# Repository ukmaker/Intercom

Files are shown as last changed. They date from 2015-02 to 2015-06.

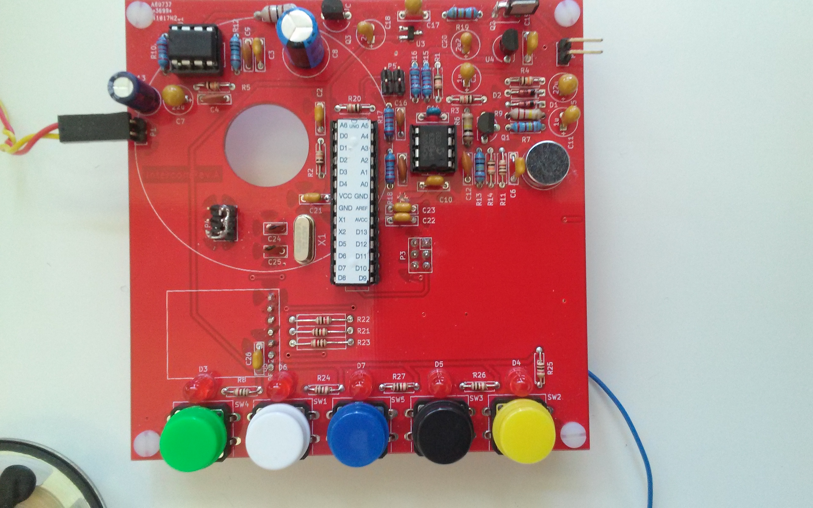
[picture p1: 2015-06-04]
Intercom_PCB_Closeup.jpg

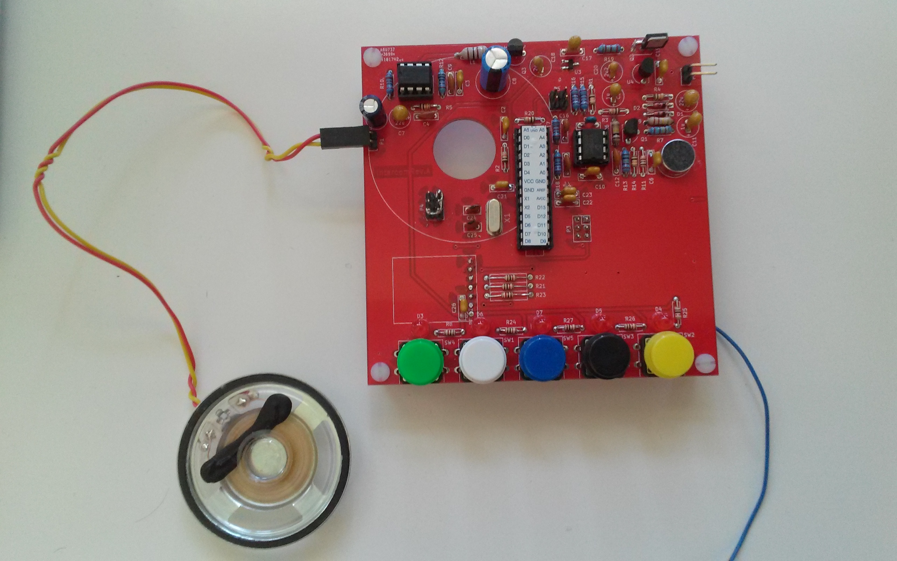
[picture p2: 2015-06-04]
Intercom_With_Speaker.jpg

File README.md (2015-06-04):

What Is it?
==================
This project implements a wireless intercom system using the RFM12B radio
module and the Atmega 328P microcontroller running the Arduino environment.

Why Does it Exist?
===================
I wanted a wireless intercom so I could stop shouting up the stairs at the kids.

The consensus on the web was that the RFM12B is not suitable for speech: challenge!

What Does It Do?
===================
Implements a five-station intercom with the following features:

  - Call each station individually (station to station)
  - Call all stations together (broadcast)
  - LED indicates which station is calling
  - Uses low power sleep modes when not in use giving up to 3 months life on a PP3 battery
  
How Does It Do It?
===================

  - Atmega 328P running at 16MHz
  - Microphone AGC circuit
  - 8-bit audio sampled at 8kHz
  - RFM12B running at 115kBaud
  - Range in excess of 20m (depends on length of aerial)

What's Wrong With It?
======================
The circuit design is fine and works well, but:

  - Battery life could be better - the RFM12B is a bit of a hog. Use a 9V wall-wart if you're bothered.
  - The PCB layout sucks. Sorry. If I had time I'd do it again using SMD parts, and I'd probably 
  use a more modern, lower power replacement for the RFM12B.
  
Dependencies
=================
Relies on my RFM12B library - a non-blocking, event-driven implementation. Get it here:

https://github.com/ukmaker/RFM12BE

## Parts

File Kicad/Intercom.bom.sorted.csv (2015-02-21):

R13 | 100K
C10 | 100n
C19 | 100n
C21 | 100n
C22 | 100n
C23 | 100n
C26 | 100n
C3 | 100n
C6 | 100n
C13 | 100u
L1 | 100u
R1 | 10K
R14 | 10K
R20 | 10K
R2 | 10K
R3 | 10K
R4 | 10K
R5 | 10K
R12 | 10R
C8 | 1200u
X1 | 16MHz
R11 | 1K
R21 | 1K
R22 | 1K
R23 | 1K
R19 | 1M
R7 | 1M
C11 | 1u
C1 | 1u
C17 | 1u
C2 | 200n
R9 | 220K
C14 | 220n
C16 | 22n
C24 | 22p
C25 | 22p
C5 | 22u
C7 | 22u
R10 | 2K2
R15 | 2K2
R16 | 2K2
R17 | 2K2
R18 | 2K2
C12 | 2n2
C18 | 2u2
C20 | 2u2
C4 | 470p
R24 | 470R
R25 | 470R
R26 | 470R
R27 | 470R
R8 | 470R
C15 | 47n
C9 | 47n
IC1 | ATMEGA328-P | DIL28
D1 | BAT43
D2 | BAT43
Q1 | BF244A | TO92
P1 | CONN_2
P2 | CONN_2
P5 | CONN_2X2
P3 | CONN_3X2
P4 | CONN_3X2
Q2 | IRFU3505
U4 | LE33CZ
D3 | LED
D4 | LED
D5 | LED
D6 | LED
D7 | LED
U1 | LM386
U3 | MCP1700T
U2 | MCP6002
MK1 | MIC9.7MM
R6 | R
U5 | RFM12B
SW1 | SW_PUSH
SW2 | SW_PUSH
SW3 | SW_PUSH
SW4 | SW_PUSH
SW5 | SW_PUSH
Reference | Value | Footprint | Datasheet
Q3 | ZTX313

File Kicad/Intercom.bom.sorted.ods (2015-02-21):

Reference | Value | Reference | Value
R13 | 100K | C18 | 2u2
C10 | 100n | C20 | 2u2
C19 | 100n | C4 | 470p
C21 | 100n | R24 | 470R
C22 | 100n | R25 | 470R
C23 | 100n | R26 | 470R
C26 | 100n | R27 | 470R
C3 | 100n | R8 | 470R
C6 | 100n | C15 | 47n
C13 | 100u | C9 | 47n
L1 | 100u | IC1 | ATMEGA328-P
R1 | 10K | D1 | BAT43
R14 | 10K | D2 | BAT43
R20 | 10K | Q1 | BF244A
R2 | 10K | P1 | CONN_2
R3 | 10K | P2 | CONN_2
R4 | 10K | P5 | CONN_2X2
R5 | 10K | P3 | CONN_3X2
R12 | 10R | P4 | CONN_3X2
C8 | 1200u | Q2 | IRFU3505
X1 | 16MHz | U4 | LE33CZ
R11 | 1K | D3 | LED
R21 | 1K | D4 | LED
R22 | 1K | D5 | LED
R23 | 1K | D6 | LED
R19 | 1M | D7 | LED
R7 | 1M | U1 | LM386
C11 | 1u | U3 | MCP1700T
C1 | 1u | U2 | MCP6002
C17 | 1u | MK1 | MIC9.7MM
C2 | 200n | R6 | R
R9 | 220K | U5 | RFM12B
C14 | 220n | SW1 | SW_PUSH
C16 | 22n | SW2 | SW_PUSH
C24 | 22p | SW3 | SW_PUSH
C25 | 22p | SW4 | SW_PUSH
C5 | 22u | SW5 | SW_PUSH
C7 | 22u | Q3 | ZTX313
R10 | 2K2
R15 | 2K2
R16 | 2K2
R17 | 2K2
R18 | 2K2
C12 | 2n2

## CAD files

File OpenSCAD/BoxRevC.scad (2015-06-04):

/**
* Intercom box rev c
* This time I might get it right.
*
* Define all panels in 2d.
* Use extrude to render in 3D to show assembly
* 2D layout can be exported to SVG for laser-cutting
**/
// Relies on using button extenders so the PCB can be 
// attached to the backplate and multiple levels are not needed
// 

// All dimensions in mm

// nice round holes
$fs=0.01;

c=5;

// kerf of the laser beam
kerf = 0;//0.2;
skerf = kerf / 2;

// Let's have a nice picture of the PCB to we can see what's going on
pcb_w = 100;
pcb_h = 100;
pcb_t = 2;
pcb_hole_t = 2.2;
pcb_hole_z = -0.1;

pcb_mth_x = 3.7;
pcb_mth_y = 3.7;
pcb_mth_x_spacing = 92.4;
pcb_mth_y_spacing = 92.7;
pcb_mth_dia = 3.0;
pcb_b_clearance = 10;
pcb_l_clearance = 5;
pcb_r_clearance = 5;
pcb_t_clearance = 10;

pcb_btn_x_spacing = 17.15;
// position of first button (is this right?)
pcb_btn_x = 15.5;
pcb_btn_y = 6.1;

btn_body_dia = 11.5;
btn_hole_dia = 12 - skerf;
btn_body_t = 4.5;

btn_rim_dia = 13;
btn_rim_t = 1.5;

btn_base_w = 10;
btn_base_h = 10;
btn_base_t = 3;
btn_ext_w = 8;
btn_ext_h = 8;
btn_ext_t = 18;


speaker_dia = 50;
speaker_inner_dia = 22;

speaker_x = 30;
speaker_y = 68;

spi_connector_top_y = 53;
spi_connector_bottom_y = 40;
spi_connector_left_x = 60;
spi_connector_width = 5;
spi_connector_height = 8;
spi_connector_base_t = 2;
spi_connector_pin_t = 8;
spi_connector_pin_w = 0.8;
spi_hole_w = 9;
spi_hole_h = 15;
spi_hole_x = 58;
spi_hole_y = 36;

microphone_x = 91.0;
microphone_y = 63.0;
microphone_dia = 8;
microphone_t = 5;

tenth_in = 2.54;
thickness = 4;

top_panel_t = 4;
top_panel_h = pcb_h + pcb_b_clearance + pcb_t_clearance;
top_panel_w = pcb_w + pcb_r_clearance + pcb_l_clearance + 2 * thickness;


tongue_length = 20;
tongue_depth = thickness;

box_h = btn_ext_t 
	+ 1 * top_panel_t 
	+ btn_base_t + btn_rim_t
	+ pcb_t 
	+ spi_connector_pin_t;


base_z = -spi_connector_pin_t;// - top_panel_t;

top_bottom_gap = pcb_t+btn_base_t+btn_ext_t+btn_rim_t + spi_connector_pin_t;
side_panel_h = top_bottom_gap + 2*top_panel_t;

side_panel_tongue_offset = 
  ((side_panel_h - 2*top_panel_t) - tongue_length) / 2;

side_panel_ul_groove_xy = 
  (side_panel_h - tongue_length) / 2;

ul_panel_h = side_panel_h - 2 * top_panel_t;

// Top-level 2D modules
// The PCB mounting holes
// A separate module since we need them on the bottom box plate as well
module mounting_holes() {
		mounting_hole(pcb_mth_x,                   pcb_mth_y);
		mounting_hole(pcb_mth_x+pcb_mth_x_spacing, pcb_mth_y);
		mounting_hole(pcb_mth_x+pcb_mth_x_spacing, pcb_mth_y+pcb_mth_y_spacing);
		mounting_hole(pcb_mth_x,                   pcb_mth_y+pcb_mth_y_spacing);
}

module mounting_hole(x, y) {
	translate([x,y,0])
	circle(r=pcb_mth_dia/2);
}

// The PCB with the speaker outline and hole
module pcb() {

	difference() {
        square([pcb_w, pcb_h]);
		translate([speaker_x, speaker_y,  0]) color("Blue") speaker_hole();
        mounting_holes();
    }

    // a circle to show where the speaker goes
    color("Black")
	translate([speaker_x, speaker_y,  0]) {
        difference() {
            circle(r=speaker_dia/2);
            circle(r=(speaker_dia/2)-1);
        }
    }
    
    // a circle to show where the microphone goes
    	
	color("Black")
	translate([microphone_x,microphone_y,0]) {
        difference() {
            circle(r=microphone_dia/2);
            circle(r=(microphone_dia/2)-1);
        }
    }
}

module speaker_hole() {
		circle(r=speaker_inner_dia/2);
}

module tongue() {
    square([tongue_length, tongue_depth]);
}

module spi_connector() {

	translate([spi_connector_left_x, spi_connector_bottom_y, -spi_connector_base_t])
	color("black")
	cube([spi_connector_width, spi_connector_height, spi_connector_base_t]);
	color("Gold") {
		// the pins
		spi_pin(spi_connector_left_x,          spi_connector_bottom_y);
		spi_pin(spi_connector_left_x+tenth_in, spi_connector_bottom_y);

		spi_pin(spi_connector_left_x,          spi_connector_bottom_y+tenth_in);
		spi_pin(spi_connector_left_x+tenth_in, spi_connector_bottom_y+tenth_in);

		spi_pin(spi_connector_left_x,          spi_connector_bottom_y+2*tenth_in);
		spi_pin(spi_connector_left_x+tenth_in, spi_connector_bottom_y+2*tenth_in);

	}
}

module spi_pin(x,y) {
	translate([x+1,y+1,-spi_connector_pin_t])
		cube([spi_connector_pin_w, spi_connector_pin_w, spi_connector_pin_t]);
}

// The blank for the top or bottom
module top_bottom() {
    
    square([top_panel_w, top_panel_h]);
	
	translate([tongue_length,-tongue_depth,0])
		tongue();
	
	translate([top_panel_w-2*tongue_length, -tongue_depth,0])
		tongue();
	
	translate([tongue_length,top_panel_h,0])
		tongue();
	
	translate([top_panel_w-2*tongue_length, top_panel_h,0])
		tongue();
	
}

module bottom() {
    difference() {
		translate([-(pcb_l_clearance + thickness),-(pcb_b_clearance+thickness),0]) 
        top_bottom();
        mounting_holes();
        spi_hole();
    }
}


module spi_hole() {
    translate([spi_hole_x, spi_hole_y,0])
    square([spi_hole_w, spi_hole_h]);
}

module top_microphone_hole(vec) {
	
	translate([vec[0]+microphone_x,vec[1]+microphone_y,0])
		circle(r=0.5);
}

module top_speaker_hole(vec) {
	
	translate([vec[0]+speaker_x,vec[1]+speaker_y,0])
		circle(r=0.6);
}

function point(radius, theta) =
 [radius * cos(theta), radius * sin(theta)];

module top_microphone_holes() {
	for(s = [ [0,1], [4,8]]) {

		for(i = [0:1:s[1]-1]) {
            top_microphone_hole(point(s[0], i*360/s[1]));
		}
	}
}

module top_speaker_holes() {
	for(s = [ [0,1], [5,8], [10, 16], [15, 24], [20, 32]]) {

		for(i = [0:1:s[1]-1]) {
            top_speaker_hole(point(s[0], i*360/s[1]));
		}
	}
}

module button_hole(x,y) {
    translate([x,y,0]) circle(r=btn_hole_dia/2);
}

module button_holes() {
    button_hole(pcb_btn_x + pcb_btn_x_spacing*0,pcb_btn_y);
    button_hole(pcb_btn_x + pcb_btn_x_spacing*1,pcb_btn_y);
    button_hole(pcb_btn_x + pcb_btn_x_spacing*2,pcb_btn_y);
    button_hole(pcb_btn_x + pcb_btn_x_spacing*3,pcb_btn_y);
    button_hole(pcb_btn_x + pcb_btn_x_spacing*4,pcb_btn_y);
}

module top_holes() {
    button_holes();
    top_microphone_holes();
    top_speaker_holes();
}

module top() {
	
	difference() {
		translate([-(pcb_l_clearance + thickness),-(pcb_b_clearance+thickness),0]) 
        top_bottom();
        top_holes();
	}
}

module upper_lower() {
	
    difference() {
        // basic upper or lower panel
        square([top_panel_w, side_panel_h]);
        
        upper_lower_grooves();

        // Remove the tongues at the left and right
        translate([0, side_panel_ul_groove_xy, 0])
          groove_l();
        
        translate([top_panel_w-tongue_depth, side_panel_ul_groove_xy,0])
          groove_r();
	}
}

module upper_lower_grooves() {
    // remove the lower grooves
    translate([tongue_length,0,0])
       groove_b();
    
    translate([top_panel_w-2*tongue_length,0])
        groove_b();

 
    // remove the upper grooves
    translate([tongue_length,side_panel_h-tongue_depth,0])
       groove_t();
    
    translate([top_panel_w-2*tongue_length,side_panel_h-tongue_depth,0])
        groove_t();

 
}

module groove_l() {
    remove_l(tongue_depth,tongue_length);
}
module groove_r() {
    remove_r(tongue_depth,tongue_length);
}

module groove_t() {
    remove_t(tongue_length,tongue_depth);
}
module groove_b() {
    remove_b(tongue_length,tongue_depth);
}

module remove_l(w,h) {
    // actual shape needs to be smaller by the amount of kerf
    // and moved to leave space for the kerf
    translate([-skerf,skerf,0])
    square([w+kerf,h-kerf]);
}

module remove_r(w,h) {
    // actual shape needs to be smaller by the amount of kerf
    // and moved to leave space for the kerf
    translate([skerf,skerf,0])
    square([w+kerf,h-kerf]);
}

module remove_t(w,h) {
    // actual shape needs to be smaller by the amount of kerf
    // and moved to leave space for the kerf
    translate([skerf,skerf,0])
    square([w-kerf,h+kerf]);
}

module remove_b(w,h) {
    // actual shape needs to be smaller by the amount of kerf
    // and moved to leave space for the kerf
    translate([skerf,-skerf,0])
    square([w-kerf,h+kerf]);
}

module left_right() {
    square([ul_panel_h, top_panel_h]);
    
    translate([side_panel_tongue_offset,-tongue_depth, 0])
      tongue();
    translate([side_panel_tongue_offset,top_panel_h, 0])
      tongue();
}
 

//translate([0,0,-1]) bottom();
//pcb();
//translate([0,0,1]) top();

//left_right();

//upper_lower();

module perspex(alpha=1)
{
	h = thickness;
	color("White",alpha) 
        linear_extrude(height=h,convexity=c,center=true) 
            for (i = [0 : $children-1]) children(i);
}

module assembled() {
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

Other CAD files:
OpenSCAD/BoxRevA.scad
OpenSCAD/BoxRevB.scad

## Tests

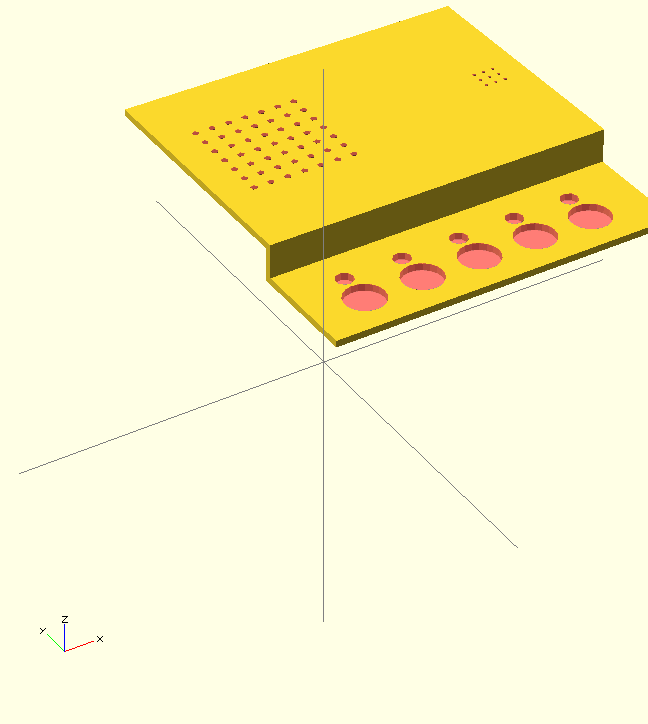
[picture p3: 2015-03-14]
OpenSCAD/test.png

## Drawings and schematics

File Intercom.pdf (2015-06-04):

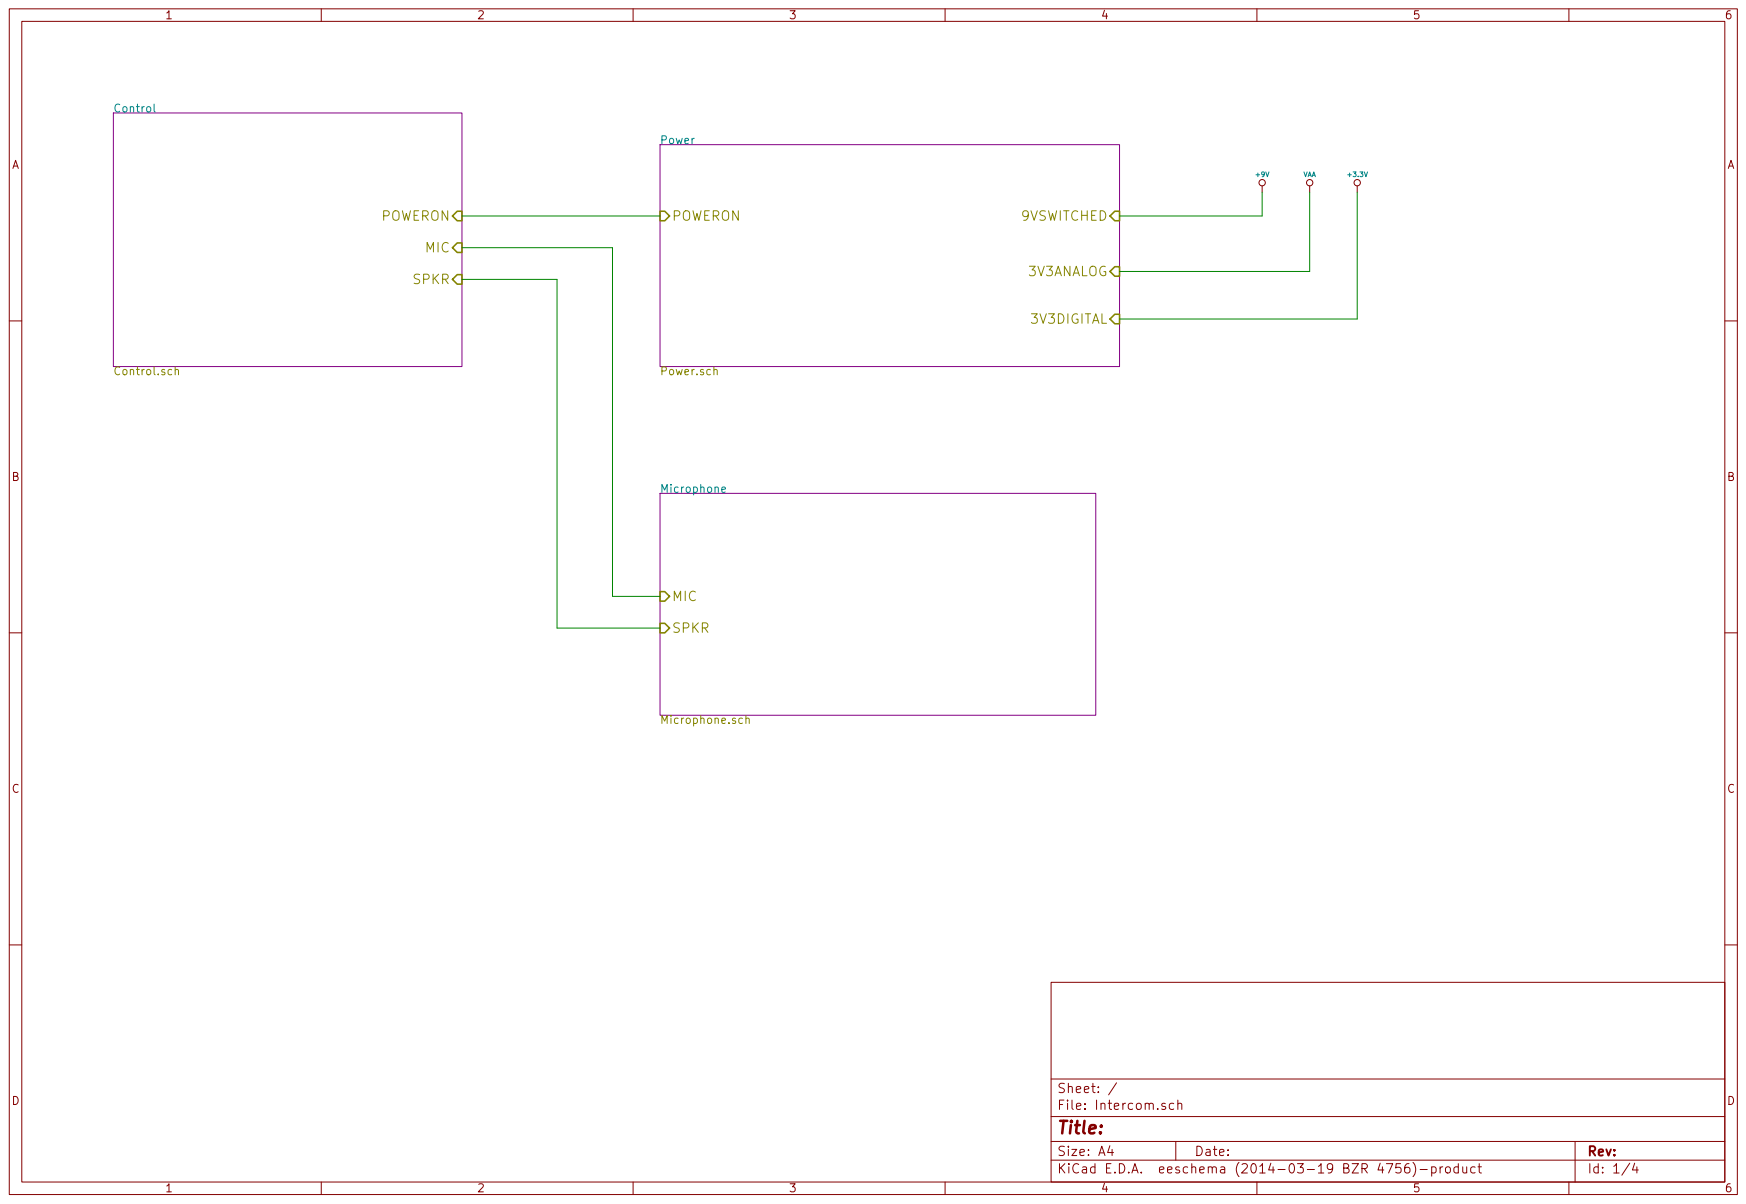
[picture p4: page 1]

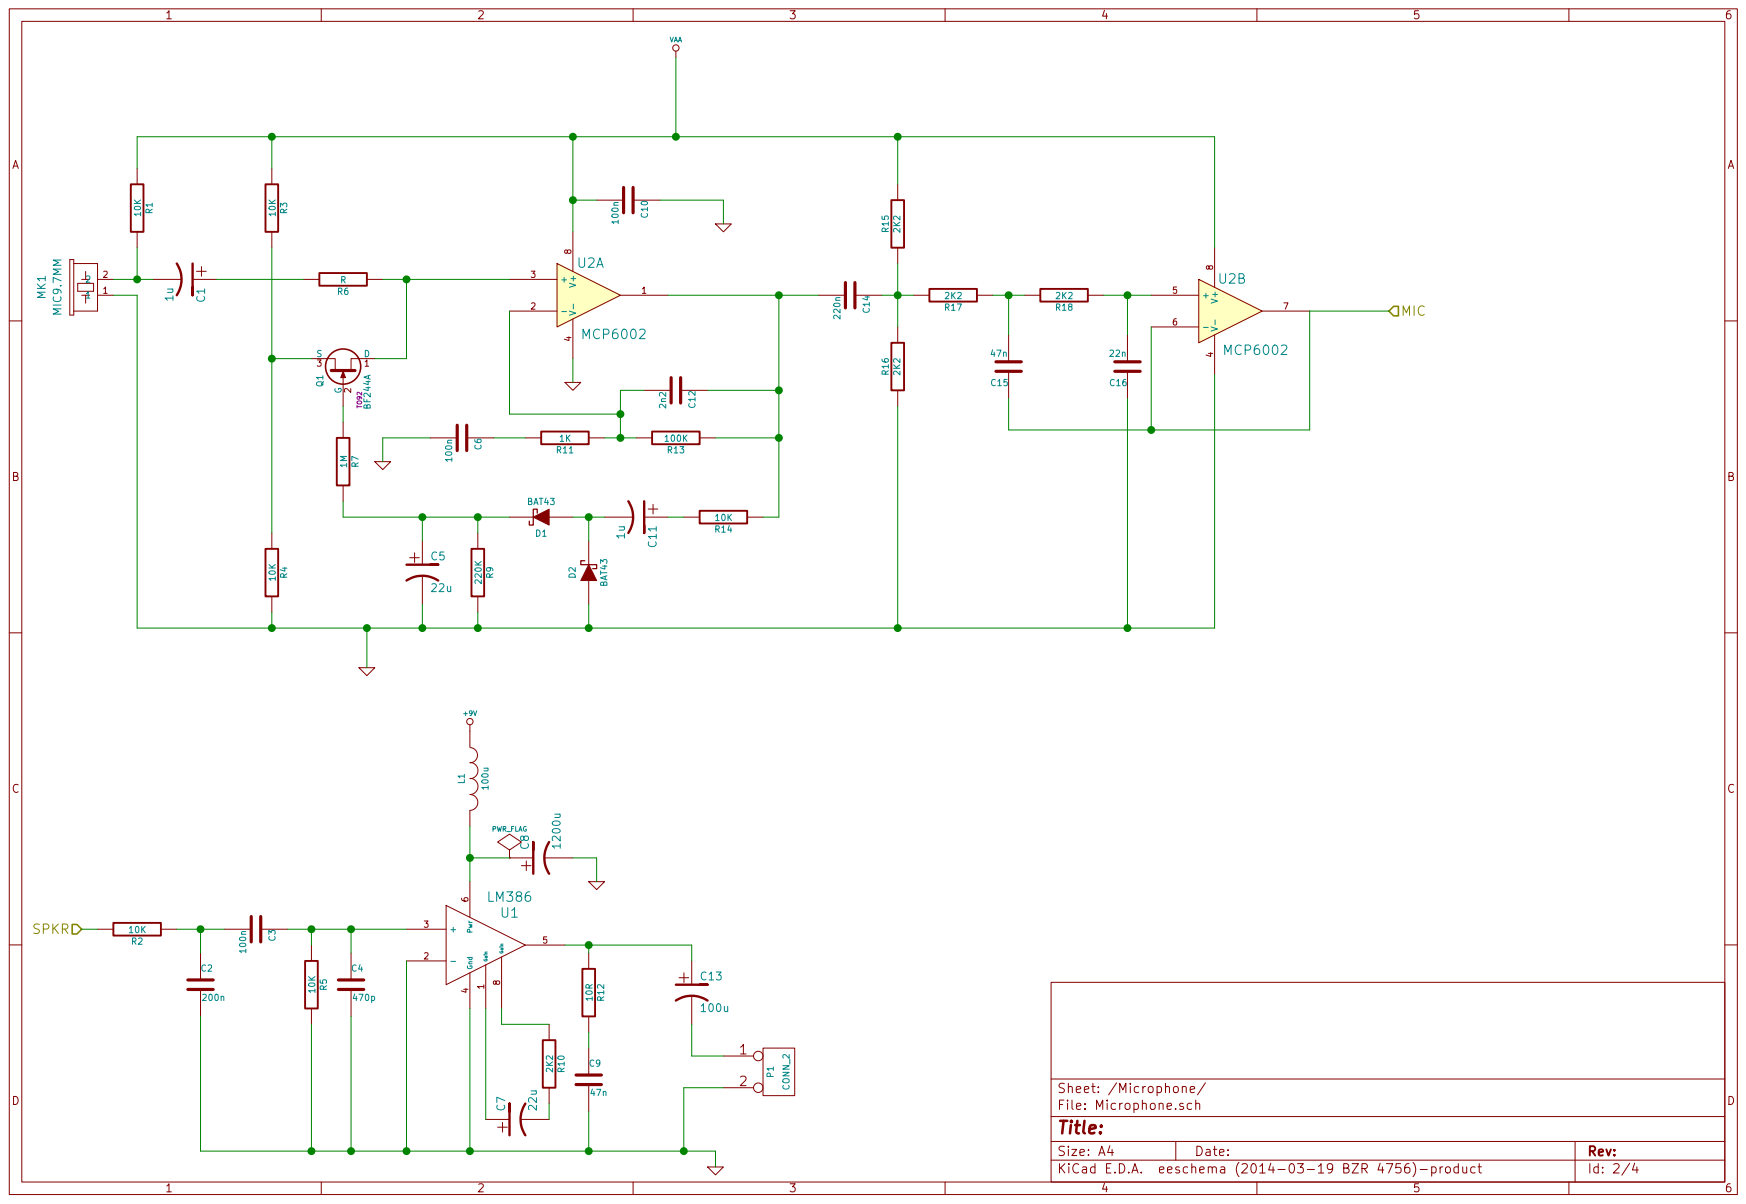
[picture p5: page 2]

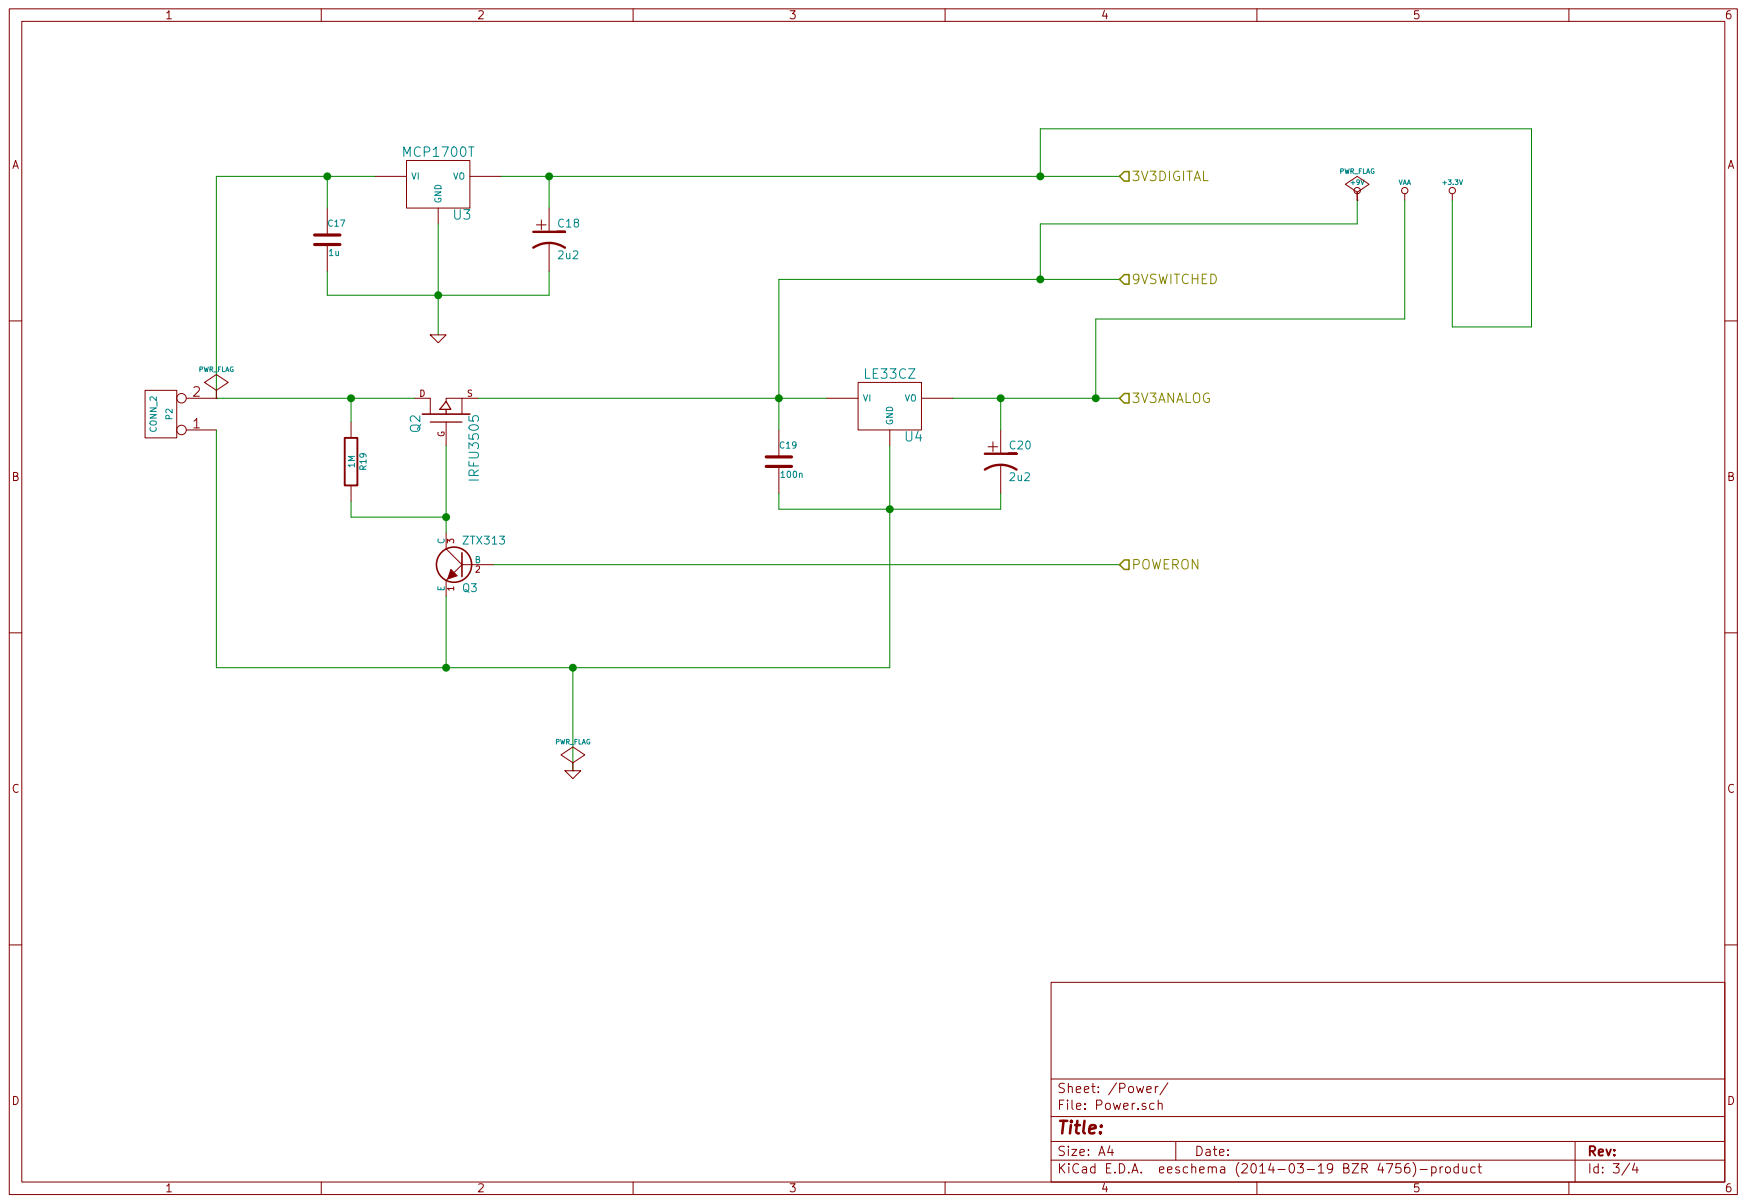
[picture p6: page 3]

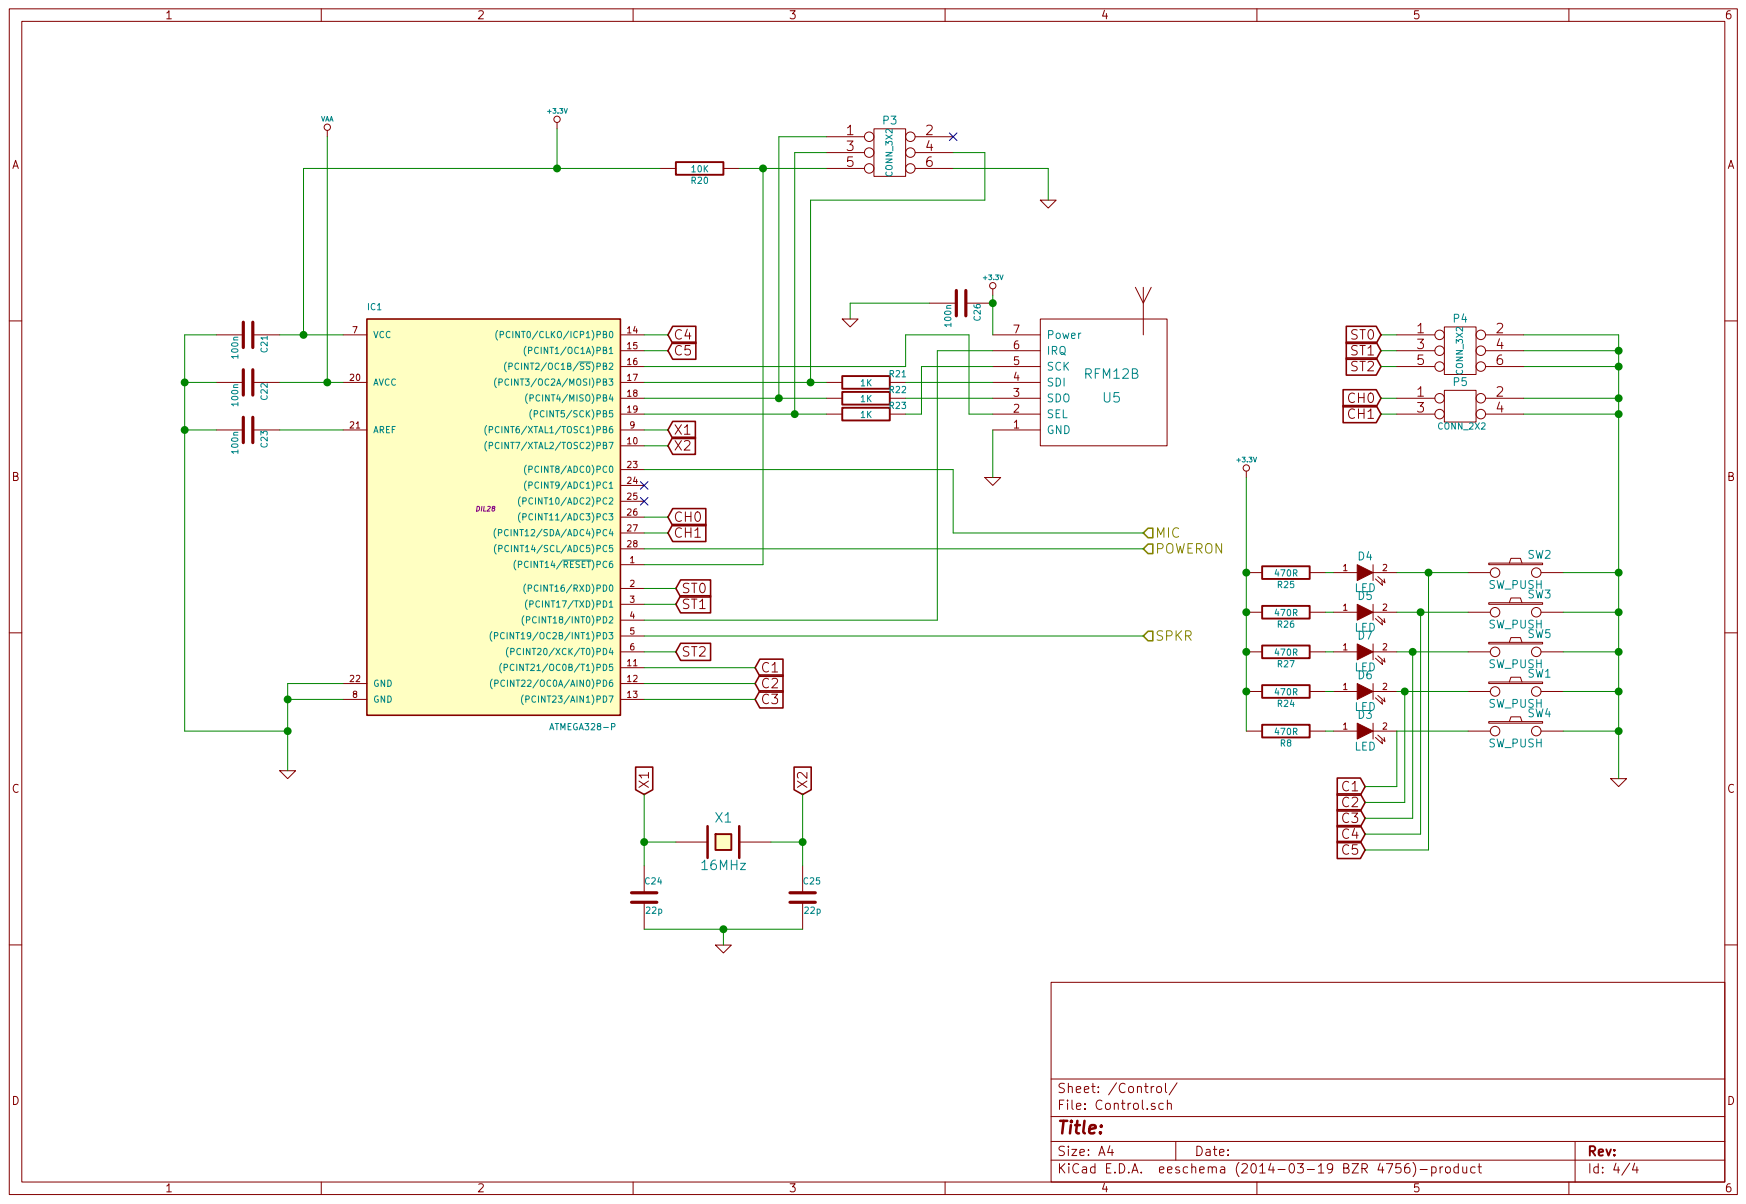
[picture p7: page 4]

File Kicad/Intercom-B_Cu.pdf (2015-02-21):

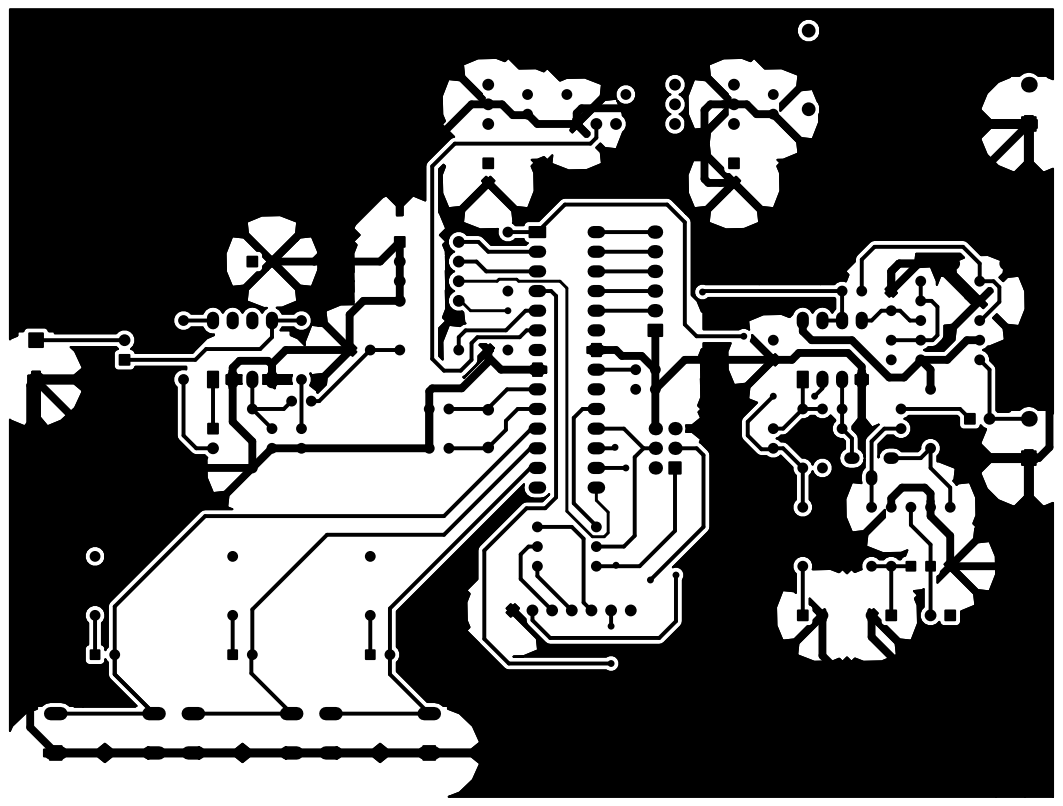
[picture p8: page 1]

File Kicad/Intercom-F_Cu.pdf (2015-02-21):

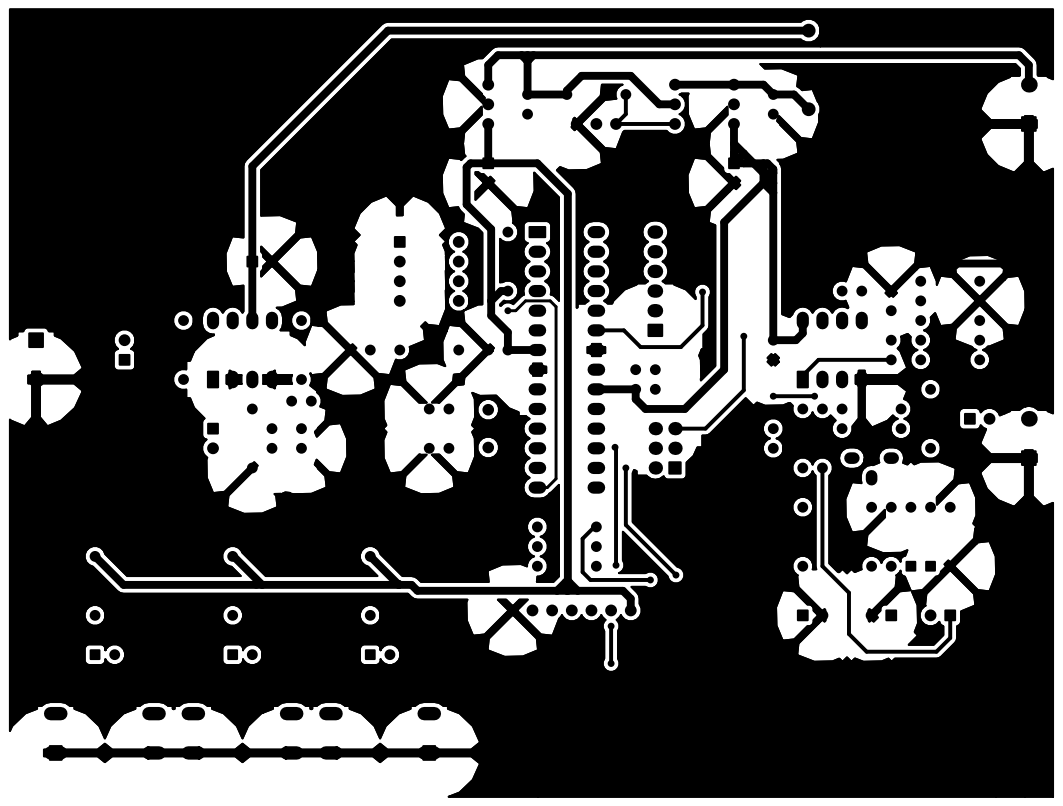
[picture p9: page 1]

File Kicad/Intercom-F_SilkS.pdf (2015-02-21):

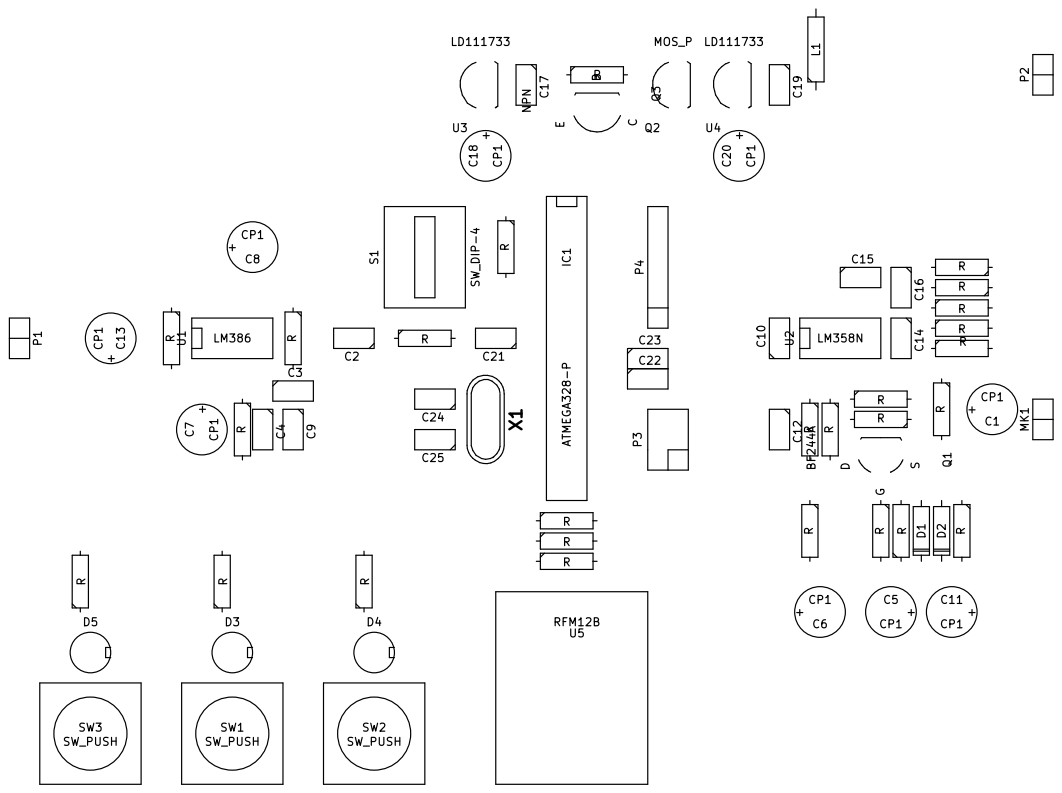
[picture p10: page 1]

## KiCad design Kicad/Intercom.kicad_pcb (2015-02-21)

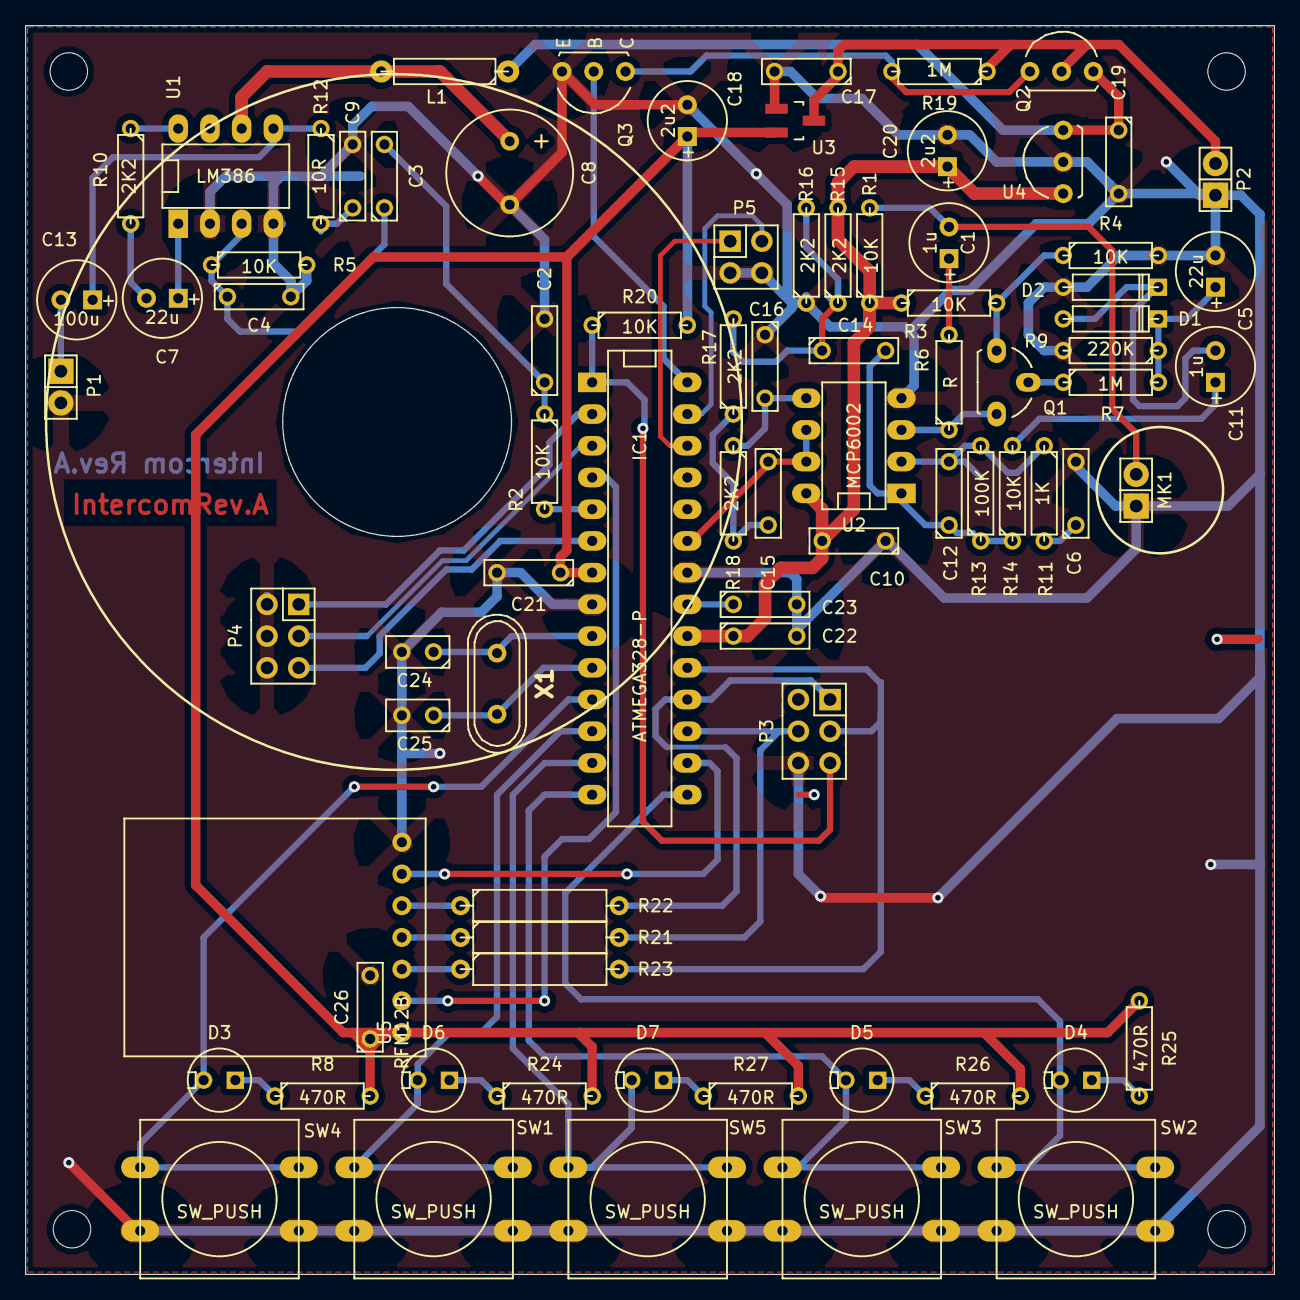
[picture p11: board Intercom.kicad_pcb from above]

Board: 2 copper layers, 100.0 x 100.0 mm, 86 parts (0 on the bottom side), 59 nets.

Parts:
C1, C11: 1u; C1V7
C2: 200n; C2
C3, C6, C10, C19, C21, C22, C23, C26: 100n; C2
C4: 470p; C2
C5, C7: 22u; C1V7
C8: 1200u; Elko_vert_20x10mm_RM5
C9, C15: 47n; C2
C12: 2n2; C2
C13: 100u; C1V7
C14: 220n; C2
C16: 22n; C2
C17: 1u; C2
C18, C20: 2u2; C1V7
C24, C25: 22p; C1
D1, D2: BAT43; D3
D3, D4, D5, D6, D7: LED; LEDV
IC1: ATMEGA328-P; DIP-28__300_ELL
L1: 100u; R4-LARGE_PADS
MK1: MIC9.7MM; Socket_Strip_Straight_1x02
MountingHole_3mm, MountingHole_3mm#2, MountingHole_3mm#3, MountingHole_3mm#4: VAL**; MountingHole_3mm
P1, P2: CONN_2; Socket_Strip_Straight_1x02
P3, P4: CONN_3X2; Socket_Strip_Straight_2x03
P5: CONN_2X2; Socket_Strip_Straight_2x02
Q1: BF244A; TO-92-FET-molded-wide-oval-SGD
Q2: IRFU3505; TO-92-Free-inline-wide
Q3: ZTX313; TO-92-Bipolar-inline-wide-CBE
R1, R2, R3, R4, R5, R14, R20: 10K; R3
R6: R; R3
R7, R19: 1M; R3
R8, R24, R25, R26, R27: 470R; R3
R9: 220K; R3
R10, R15, R16, R17, R18: 2K2; R3
R11: 1K; R3
R12: 10R; R3
R13: 100K; R3
R21, R22, R23: 1K; R5
SW1, SW2, SW3, SW4, SW5: SW_PUSH; SW_PUSH-12mm
U1: LM386; DIP-8__300_ELL
U2: MCP6002; DIP-8__300_ELL
U3: MCP1700T; SOT23_Transistor_Handsoldering_RevB_14Mar2014
U4: LE33CZ; TO-92-Free-inline-wide
U5: RFM12B
X1: 16MHz; Crystal_HC49-U_Vertical

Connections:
+3.3V: C18.1, C21.1, C26.1, IC1.7, R8.2, R20.2, R24.2, R25.2, R26.2, R27.2, U3.VO, U5.7
+9V: C19.1, L1.1, Q2.S, U4.VI
/Control/MIC: C15.1, IC1.23, U2.6, U2.7
/Control/POWERON: IC1.28, Q3.2
/Control/SPKR: IC1.5, R2.2
C1: D3.2, IC1.11, SW4.1
C2: D6.2, IC1.12, SW1.1
C3: D7.2, IC1.13, SW5.1
C4: D5.2, IC1.14, SW3.1
C5: D4.2, IC1.15, SW2.1
CH0: IC1.26, P5.1
CH1: IC1.27, P5.3
GND: C2.2, C4.2, C5.2, C6.2, C8.2, C9.2, C10.1, C16.1, C17.2, C18.2, C19.2, C20.2, C21.2, C22.2, C23.2, C24.2, C25.2, C26.2, D2.1, IC1.8, IC1.22, MK1.1, P1.2, P2.1, P3.6, P4.2, P4.4, P4.6, P5.2, P5.4, Q3.1, R4.2, R5.2, R9.2, R16.1, SW1.2, SW2.2, SW3.2, SW4.2, SW5.2, U1.2, U1.4, U2.4, U3.GND, U4.GND, U5.1
unnamed: C1.1, R6.2
unnamed: C1.2, MK1.2, R1.2
unnamed: C2.1, C3.2, R2.1
unnamed: C3.1, C4.1, R5.1, U1.3
unnamed: C5.1, D1.2, R7.2, R9.1
unnamed: C6.1, R11.2
unnamed: C7.1, U1.1
unnamed: C7.2, R10.2
unnamed: C8.1, L1.2, U1.6
unnamed: C9.1, R12.2
unnamed: C11.1, R14.2
unnamed: C11.2, D1.1, D2.2
unnamed: C12.1, C14.2, R13.1, R14.1, U2.1
unnamed: C12.2, R11.1, R13.2, U2.2
unnamed: C13.1, R12.1, U1.5
unnamed: C13.2, P1.1
unnamed: C14.1, R15.1, R16.2, R17.2
unnamed: C15.2, R17.1, R18.2
unnamed: C16.2, R18.1, U2.5
unnamed: C17.1, P2.2, Q2.D, R19.1, U3.VI
unnamed: C23.1, IC1.21
unnamed: D3.1, R8.1
unnamed: D4.1, R25.1
unnamed: D5.1, R26.1
unnamed: D6.1, R24.1
unnamed: D7.1, R27.1
unnamed: IC1.1, P3.5, R20.1
unnamed: IC1.4, U5.6
unnamed: IC1.16, U5.2
unnamed: IC1.17, P3.4, R21.2
unnamed: IC1.18, P3.1, R22.2
unnamed: IC1.19, P3.3, R23.2
unnamed: Q1.1, R6.1, U2.3
unnamed: Q1.2, R7.1
unnamed: Q1.3, R3.2, R4.1
unnamed: Q2.G, Q3.3, R19.2
unnamed: R10.1, U1.8
unnamed: R21.1, U5.4
unnamed: R22.1, U5.3
unnamed: R23.1, U5.5
ST0: IC1.2, P4.1
ST1: IC1.3, P4.3
ST2: IC1.6, P4.5
VAA: C10.2, C20.1, C22.1, IC1.20, R1.1, R3.1, R15.2, U2.8, U4.VO
X1: C24.1, IC1.9, X1.1
X2: C25.1, IC1.10, X1.2

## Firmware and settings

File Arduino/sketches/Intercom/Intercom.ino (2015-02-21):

#include <Board.h>
#include <RFM12BE.h>
#include <Interface.h>

#include <avr/sleep.h>
#include <avr/power.h>

// For RFM12B
#define NETWORKID 99

// Size of the audio buffer
#define BUFSIZE 64
// Baud rate of the radio
#define RFM_115KBAUD 3

#define INTERCOM_MODE_START_RX 1
#define INTERCOM_MODE_RX 2
#define INTERCOM_MODE_TX 3

// The delay between received packets should be less than this
#define RX_TIMEOUT_TICKS 64

// If no activity for one second, go back to sleep
#define IDLE_TIMEOUT_TICKS 8000

// Events for the whole intercom
#define INTERCOM_EVENT_TX_BUF_FULL   0x01
#define INTERCOM_EVENT_IDLE_TIMEOUT  0x02
#define INTERCOM_EVENT_RX_TIMEOUT    0x04

RFM12BE radio;
Board board;
Interface interface;


// Volatile variables are modified by the ISRs
volatile bool txBufReady;
volatile bool dacDataAvailable = false;
volatile uint8_t intercomEvents;
volatile bool wokenByRx = false;
volatile int bufPtr;

uint8_t* buf;


int intercomMode = INTERCOM_MODE_START_RX;

unsigned long debounceTicks = 0;
unsigned long lastPacketReceivedTicks = 0;
unsigned long startedIdlingTicks = 0;

int destination = -1;



void setup() {

    // switch off analog comparator to save a bit of power
    ACSR = B10000000;

    lastPacketReceivedTicks=0;
    startedIdlingTicks=0;

    board.initialise();
    board.startTimers();
    board.setButtonDownHandler(buttonDownEventHandler);
    board.setButtonUpHandler(buttonUpEventHandler);

    radio.setInterface(&interface);
    radio.initialise(board.boardId, RF12_433MHZ, NETWORKID, 0 , RFM_115KBAUD, 0);
    radio.registerEventHandler(EVENT_RX_PACKET, packetReceivedEventHandler);
    radio.registerEventHandler(EVENT_TX_READY, packetSentEventHandler);

    attachInterrupt(0, radioInterruptHandler, LOW);

    radio.startReceive();
    board.setDACEnabled(true);
}

void loop() {

    // button events override everything else
    board.handleButtonEvents();

    // handle radio events
    radio.dispatchEvents();

    updateTimeouts();       
    handleTimeoutEvents();
}


bool buttonDownEventHandler() {

    // Turn on the ADC
    board.setDACEnabled(false);
    intercomEvents = 0;
    board.setAnalogEnabled(true);

    // abort any current radio operations and get ready to send
    buf = radio.startTransmit();
    bufPtr=0;
    intercomMode = INTERCOM_MODE_TX;
    board.setADCEnabled(true);
    // Turn off any LEDs which were on because we my have been in receive mode
    // otherwise we'll stay stuck in tx forever
    board.initialiseButtons();
    destination = board.readButtons();
    return true;
}

bool buttonUpEventHandler() {

    // stop the ADC interrupt handler
    board.setADCEnabled(false);
    intercomEvents = 0;
    // stop the radio transmitter and start receiving
    radio.startReceive();
    intercomMode = INTERCOM_MODE_START_RX;
    // turn off the analog for now - no point in using power until we
    // have received a packet to playback
    board.setAnalogEnabled(false);
    board.setDACEnabled(true);
    return true;
}

bool packetReceivedEventHandler() {
    buf = radio.getBuffer();
    bufPtr = 0;

    if(intercomMode == INTERCOM_MODE_START_RX) {
        board.setAnalogEnabled(true);
        board.setDACEnabled(true);
        intercomMode = INTERCOM_MODE_RX;
    }
    lastPacketReceivedTicks = board.ticks;
    board.showSource(radio.getSenderId());
    dacDataAvailable = true;

    return true;
}

bool packetSentEventHandler() {

    if(intercomEvents & INTERCOM_EVENT_TX_BUF_FULL) {
        // ready to send the next packet
        radio.send(board.buttons, BUFSIZE);
        intercomEvents &= ~INTERCOM_EVENT_TX_BUF_FULL;
        // finished with this event
        return true;
    }

    // haven't finished with this radio event yet
    return false;
}

bool updateTimeouts() {

    if((intercomMode != INTERCOM_MODE_RX) && (intercomMode != INTERCOM_MODE_START_RX)) {
        return false;
    }

    uint16_t delay = board.ticks - lastPacketReceivedTicks;

    if((intercomMode == INTERCOM_MODE_START_RX) && (delay > IDLE_TIMEOUT_TICKS)) {
        intercomEvents |= INTERCOM_EVENT_IDLE_TIMEOUT;
    } 
    else if(delay > RX_TIMEOUT_TICKS) {
        intercomEvents |= INTERCOM_EVENT_RX_TIMEOUT;
    }
}

void rxTimeoutEventHandler() {
    board.setAnalogEnabled(false);
    board.initialiseButtons();
    intercomMode = INTERCOM_MODE_START_RX;
}

void handleTimeoutEvents() {
    if(intercomEvents & INTERCOM_EVENT_RX_TIMEOUT) {
        rxTimeoutEventHandler();
        intercomEvents &= ~INTERCOM_EVENT_RX_TIMEOUT;
    }

    if(intercomEvents & INTERCOM_EVENT_IDLE_TIMEOUT) {
        idleTimeoutEventHandler();
        intercomEvents &= ~INTERCOM_EVENT_IDLE_TIMEOUT;
    }
}

void idleTimeoutEventHandler() {
    byte adcsra = ADCSRA;
    byte admux = ADMUX;
    byte didr0 = DIDR0;
    byte didr1 = DIDR1;
    byte prr = PRR;

    // Turn off power to the analog section
    board.setAnalogEnabled(false);

    // put the radio into snooze mode
    // so that it wakes up every 350ms to check for a packet
    radio.sleepLDC(0x0260,1);

    noInterrupts();
    sleep_enable();
    set_sleep_mode(SLEEP_MODE_PWR_DOWN);

    // stop watch-dog timer
    /* Clear WDRF in MCUSR */
    MCUSR &= ~(1<<WDRF);
    /* Write logical one to WDCE and WDE */
    /* Keep old prescaler setting to prevent unintentional time-out */
    WDTCSR |= (1<<WDCE) | (1<<WDE);
    /* Turn off WDT */
    WDTCSR = 0x00;  

    // make sure no digital inputs are enabled on the analog pins
    DIDR0 = 0;
    DIDR1 = 0;

    // switch off the adc
    ADCSRA =0;
    ADMUX=0;

    PRR=0XFF;

    // attach a wakeup handler to the radio int pin
    attachInterrupt(0, wokenByRxInterruptHandler, LOW);
    wokenByRx = false;

    // turn off brown-out enable in software
    MCUCR = bit (BODS) | bit (BODSE);  // turn on brown-out enable select
    MCUCR = bit (BODS);        // this must be done within 4 clock cycles of above
    interrupts ();             // guarantees next instruction executed
    sleep_cpu ();              // sleep within 3 clock cycles of above
    //noInterrupts();  
    // Back from sleep here
    // Re-enable the hardware we were using
    sleep_disable();
    ADMUX = admux;
    ADCSRA = adcsra;
    PRR = prr;
    DIDR0 = didr0;
    DIDR1 = didr1;
    powerUp();
}

void wokenByRxInterruptHandler() {
    sleep_disable();
    detachInterrupt(0);
    wokenByRx = true;
}

void powerUp() {

    radio.wakeup();
    attachInterrupt(0, radioInterruptHandler, LOW);

    if(wokenByRx) {
        intercomMode = INTERCOM_MODE_START_RX;
        lastPacketReceivedTicks = board.ticks;
    } 
    else {
        intercomMode = INTERCOM_MODE_TX;
    }
}

void radioInterruptHandler() {
    RFM12BE::interruptHandler(&radio);
}

ISR(PCINT0_vect) {
    board.handleButtonInterrupt();
} 

ISR(PCINT2_vect) {
    board.handleButtonInterrupt();
} 

// The Timer1 ISR handles dac
ISR(TIMER1_COMPA_vect) {

    // count ticks during receive
    // note that this will break when it wraps. Oh well
    board.ticks++;

    if(!dacDataAvailable) {
        return;
    }

    OCR2B = buf[bufPtr++];
    if(bufPtr >= BUFSIZE) {
        dacDataAvailable = false;
    }
}

// This isn't used, but seems to be needed to trigger the ADC
ISR(TIMER1_COMPB_vect) {
    board.ticks++;
}

// The ADC ISR
ISR(ADC_vect) {

    buf[bufPtr++] = ADCH;

    if(bufPtr >= BUFSIZE) {
        buf = radio.getBuffer();
        bufPtr=0;
        intercomEvents |= INTERCOM_EVENT_TX_BUF_FULL;
    }
}

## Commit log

2015-02-21 Initial import
    [Control.sch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]
2015-03-14 Added OpenSCAD WIP
    [BoxRevA.scad, BoxRevB.scad]
2015-06-04 Added README and pictures
    [BoxRevC.scad]
